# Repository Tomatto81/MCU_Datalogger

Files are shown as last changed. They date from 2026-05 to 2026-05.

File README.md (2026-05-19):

## ⚙️ MCU Data Logger – PCB Design with KiCad  

### 📋 Project Overview

**MCU Data Logger** is a custom PCB that records sensor or system data over time.

It's built around an **ATmega328P‑AU** microcontroller and uses an **EEPROM** (24LC1025) to keep the data even after power is removed. A **DS1337 real‑time clock** timestamps every entry, so you know exactly when something happened.

The board talks to the outside world through **UART, SPI, and I2C** – you can connect it to sensors, displays, or another microcontroller. I also brought out a few spare GPIOs in case you want to add more features later.

The whole design was done in **KiCad** using a **4‑layer stackup** (signal – GND – VCC – signal) to keep noise low and routing tidy.

### 🔧 Key Features

- **4-layer PCB** – Designed and routed in KiCad.
- **ATmega328P-AU** – Main microcontroller for processing and control.
- **💾 24LC1025 EEPROM** – Non‑volatile storage for logged data.
- **⏱️ DS1337 RTC** – Real‑time clock for accurate timestamps.
- **🔌 UART, SPI, I2C** – Multiple communication interfaces.
- **📈 Spare GPIOs** – Brought out for future expansion.

---

## 🔄 Project Flow  

1️⃣ **Microcontroller (ATmega328P-AU)**  
   - Handles all system operations and manages communication.  
   - Reads and writes data to EEPROM for storage.  
   
2️⃣ **RTC Module (DS1337)**  
   - Provides accurate timestamps for logged data.  
   - Communicates via I2C with the MCU.  
   
3️⃣ **EEPROM Storage (24LC1025)**  
   - Stores logged data persistently.  
   - Connected over I2C for data transfer.  

4️⃣ **Communication Interfaces**  
   - **UART**: Serial communication for debugging/logging.  
   - **SPI & I2C**: Expandability for additional peripherals.  

5️⃣ **Power Management & PCB Layout**  
   - Designed for stable operation with proper power routing.  
   - Optimized signal paths to reduce interference and improve reliability.  

--- 

## 🖼️ PCB Design & Visualizations

### 1️⃣ Top Copper Layer
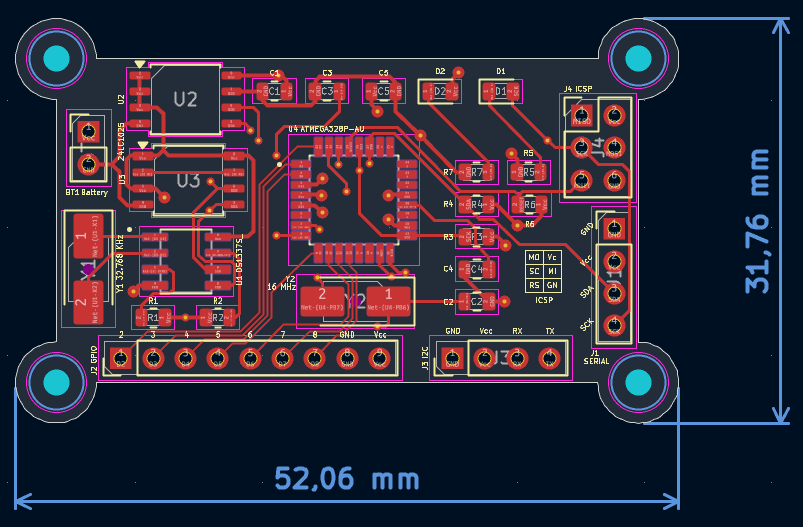
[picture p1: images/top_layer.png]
Top Copper Layer


### 2️⃣ Bottom Copper Layer
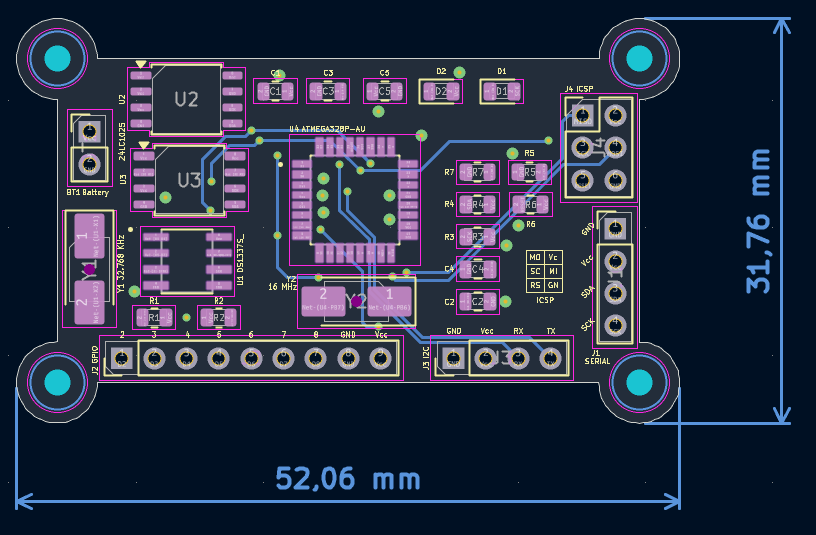
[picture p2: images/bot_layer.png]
Bottom Copper Layer
  

### 3️⃣ MCU Datalogger Schematic
MCU Datalogger Schematic  

### 4️⃣ Connectors Schematic
Connectors Schematic

### 5️⃣ 3D Model (Top & Bottom)
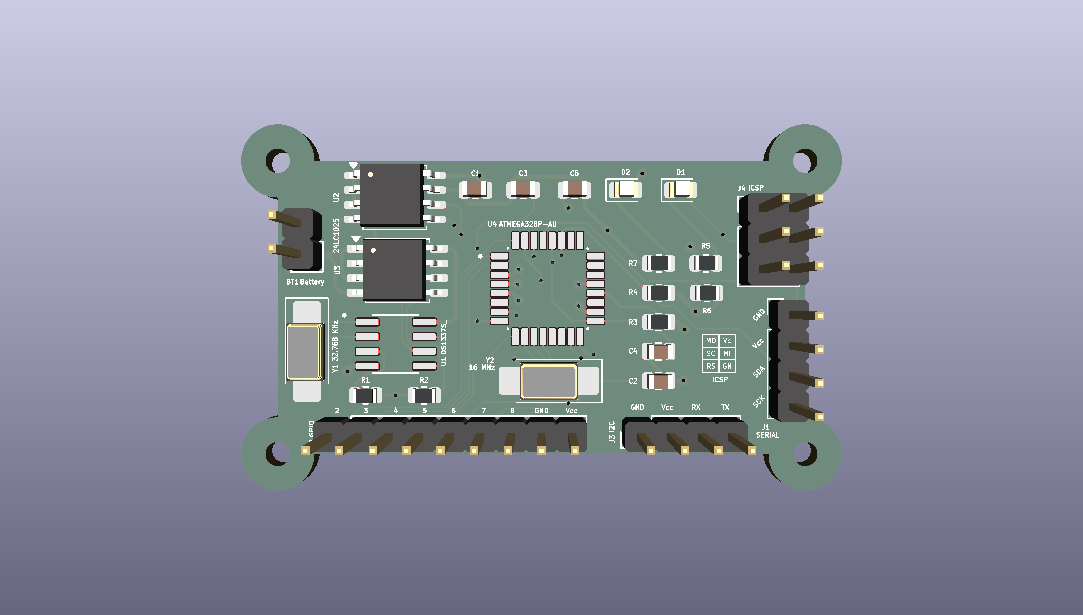
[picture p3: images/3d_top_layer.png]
3D Model - Top

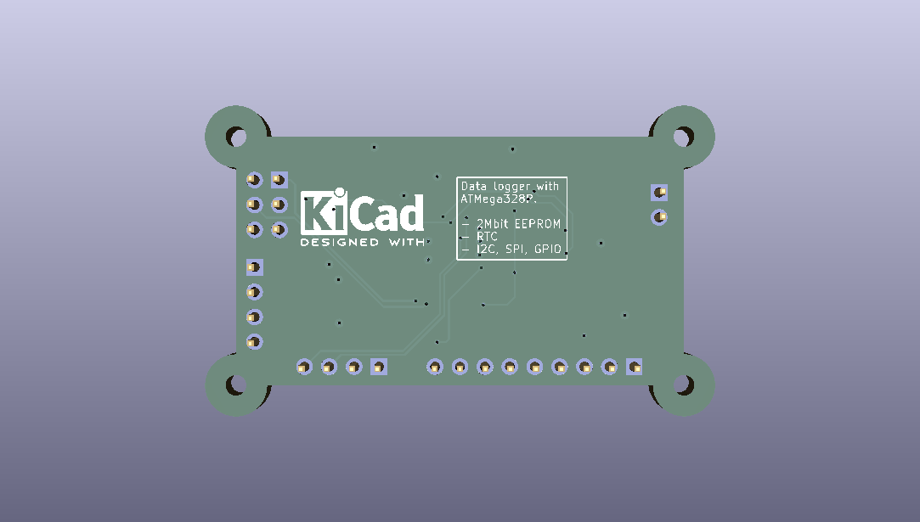
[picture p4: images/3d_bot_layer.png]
3D Model - Bottom


---

## 📥 Download & Build
The complete project files, including KiCad PCB designs and schematics, are available for download from my **GitHub repository**.

---

## 💬 Feedback & Suggestions
Please feel free to open an **issue** or leave a **comment**.

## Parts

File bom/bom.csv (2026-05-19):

 | Sourced | Placed | References | Value | Footprint | Quantity
1 |  |  | C1, C4, C5 | 100nF | C_0805_2012Metric | 3
2 |  |  | C2, C3 | 22pF | C_0805_2012Metric | 2
3 |  |  | R1, R2, R6 | 10K | R_0805_2012Metric | 3
4 |  |  | R3, R4 | 4.7K | R_0805_2012Metric | 2
5 |  |  | R5, R7 | 330 | R_0805_2012Metric | 2
6 |  |  | D1, D2 | LED | LED_0805_2012Metric | 2
7 |  |  | U2, U3 | 24LC1025 | SOIC-8_5.3x5.3mm_P1.27mm | 2
8 |  |  | U1 | DS1337S_ | SOIC127P600X175-8N | 1
9 |  |  | U4 | ATMEGA328P-AU | QFP80P900X900X120-32N | 1
10 |  |  | Y1 | 32.768 KHz | Crystal_SMD_5032-2Pin_5.0x3.2mm_HandSoldering | 1
11 |  |  | Y2 | 16 MHz | Crystal_SMD_5032-2Pin_5.0x3.2mm_HandSoldering | 1
12 |  |  | BT1 | Battery | PinHeader_1x02_P2.54mm_Vertical | 1
13 |  |  | J1, J3 | Conn_01x04_Pin | PinHeader_1x04_P2.54mm_Vertical | 2
14 |  |  | J2 | Conn_01x09_Pin | PinHeader_1x09_P2.54mm_Vertical | 1
15 |  |  | J4 | Conn_02x03_Odd_Even | PinHeader_2x03_P2.54mm_Vertical | 1

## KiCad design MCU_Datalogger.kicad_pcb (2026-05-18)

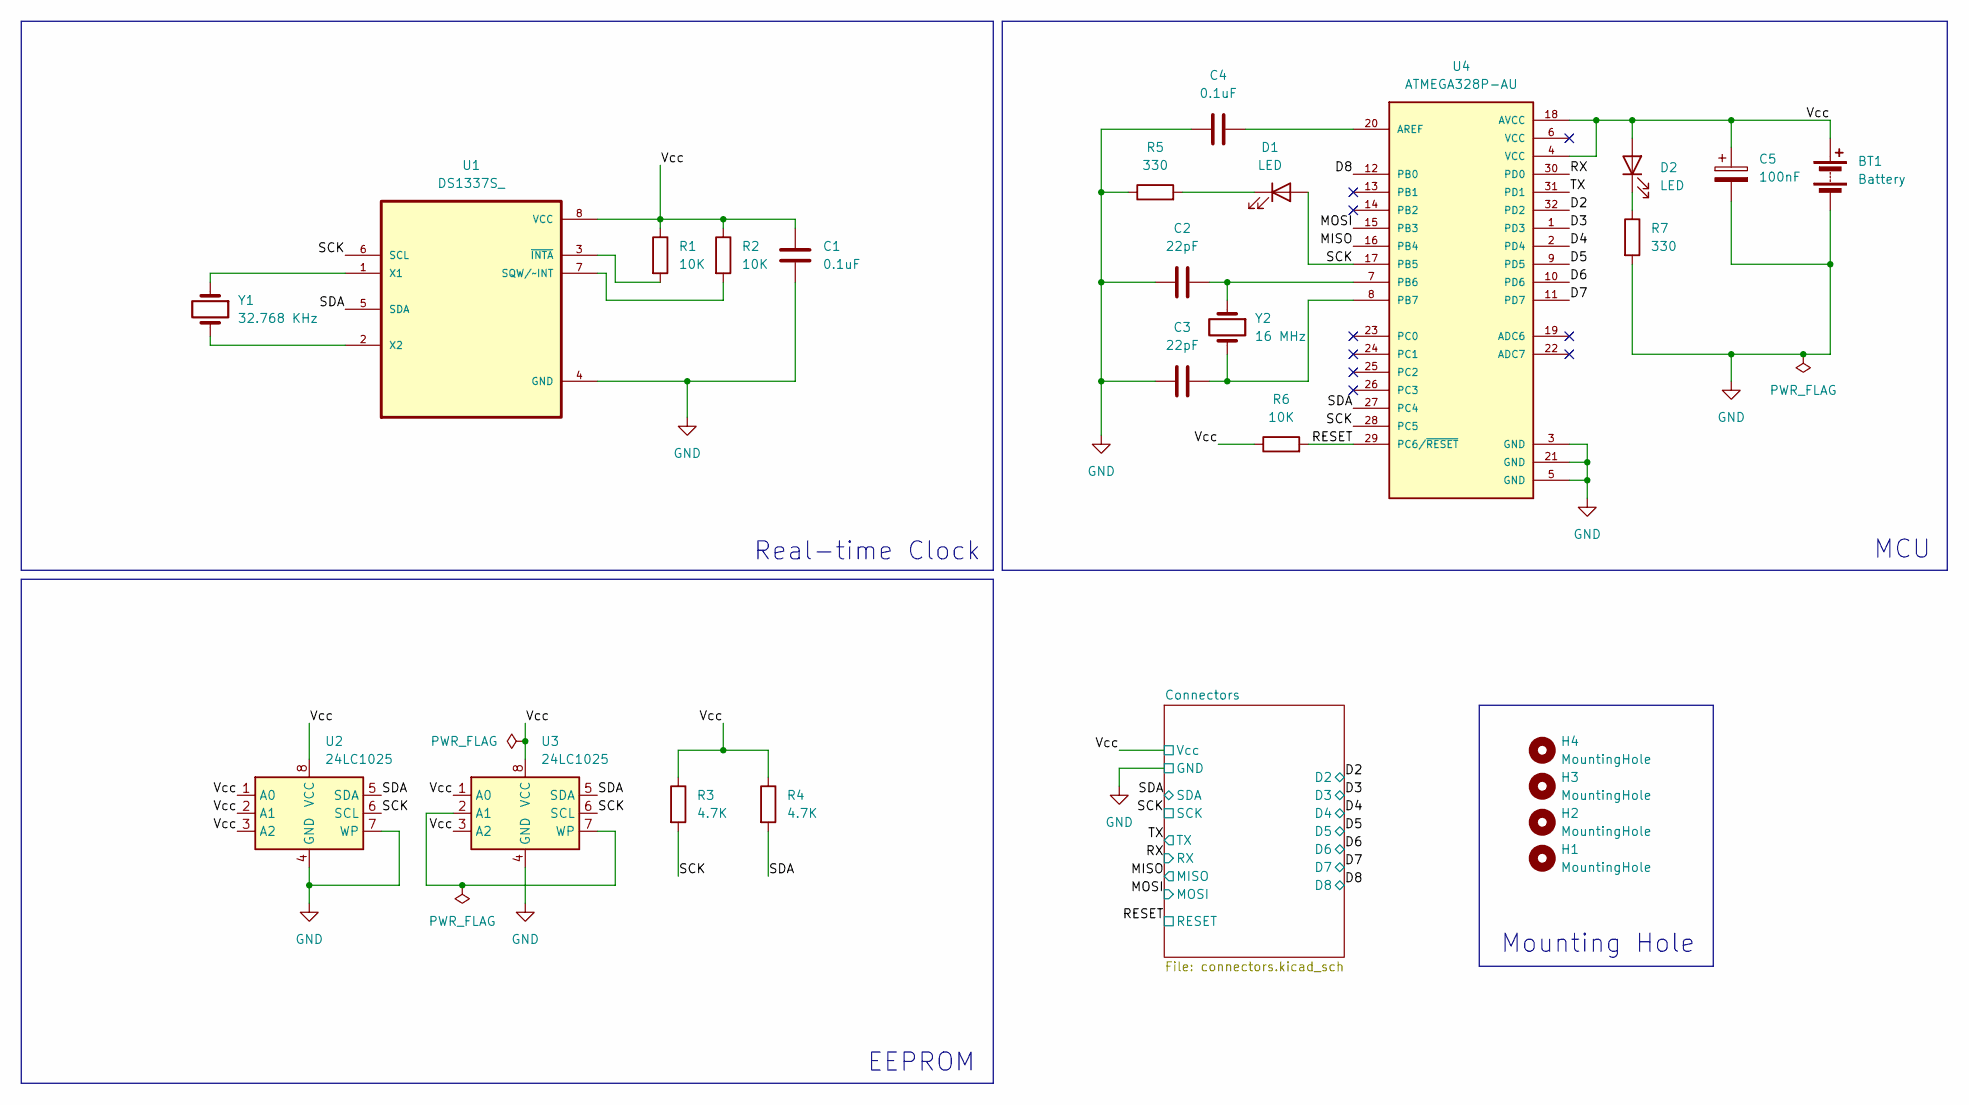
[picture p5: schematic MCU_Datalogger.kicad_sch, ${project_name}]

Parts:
BT1: Battery; PinHeader_1x02_P2.54mm_Vertical
C1, C4: 0.1uF; C_0805_2012Metric
C2, C3: 22pF; C_0805_2012Metric
C5: 100nF; C_0805_2012Metric
D1, D2: LED; LED_0805_2012Metric
H1, H2, H3, H4: MountingHole; MountingHole_2.1mm
R1, R2, R6: 10K; R_0805_2012Metric
R3, R4: 4.7K; R_0805_2012Metric
R5, R7: 330; R_0805_2012Metric
U1: DS1337S_; SOIC127P600X175-8N
U2, U3: 24LC1025; SOIC-8_5.3x5.3mm_P1.27mm
U4: ATMEGA328P-AU; QFP80P900X900X120-32N; PARTREV 8271A
Y1: 32.768 KHz; Crystal_SMD_5032-2Pin_5.0x3.2mm_HandSoldering
Y2: 16 MHz; Crystal_SMD_5032-2Pin_5.0x3.2mm_HandSoldering

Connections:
/D2: U4.32 (PD2); also elsewhere on the board
/D3: U4.1 (PD3); also elsewhere on the board
/D4: U4.2 (PD4); also elsewhere on the board
/D5: U4.9 (PD5); also elsewhere on the board
/D6: U4.10 (PD6); also elsewhere on the board
/D7: U4.11 (PD7); also elsewhere on the board
/D8: U4.12 (PB0); also elsewhere on the board
/MISO: U4.16 (PB4); also elsewhere on the board
/MOSI: U4.15 (PB3); also elsewhere on the board
/RESET: R6.2, U4.29 (PC6/~RESET); also elsewhere on the board
/RX: U4.30 (PD0); also elsewhere on the board
/SCK: D1.2 (A), R3.2, U1.6 (SCL), U2.6 (SCL), U3.6 (SCL), U4.17 (PB5), U4.28 (PC5); also elsewhere on the board
/SDA: R4.2, U1.5 (SDA), U2.5 (SDA), U3.5 (SDA), U4.27 (PC4); also elsewhere on the board
/TX: U4.31 (PD1); also elsewhere on the board
/Vcc: BT1.1 (+), C1.1, C5.1, D2.2 (A), R1.1, R2.1, R3.1, R4.1, R6.1, U1.8 (VCC), U2.1 (A0), U2.2 (A1), U2.3 (A2), U2.8 (VCC), U3.1 (A0), U3.3 (A2), U3.8 (VCC), U4.4 (VCC), U4.18 (AVCC); also elsewhere on the board
GND: BT1.2 (-), C1.2, C2.2, C3.2, C4.1, C5.2, R5.1, R7.2, U1.4 (GND), U2.4 (GND), U2.7 (WP), U3.4 (GND), U4.3 (GND), U4.5 (GND), U4.21 (GND); also elsewhere on the board
unnamed: D1.1 (K), R5.2
unnamed: D2.1 (K), R7.1
unnamed: R2.2, U1.7 (SQW/~INT)
unnamed: U1.1 (X1), Y1.1
unnamed: U1.2 (X2), Y1.2
unnamed: R1.2, U1.3 (~INTA)
unnamed: U3.2 (A1), U3.7 (WP)
unnamed: C4.2, U4.20 (AREF)
unnamed: C2.1, U4.7 (PB6), Y2.1
unnamed: C3.1, U4.8 (PB7), Y2.2

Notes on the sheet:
EEPROM
Real-time Clock
Mounting Hole
MCU

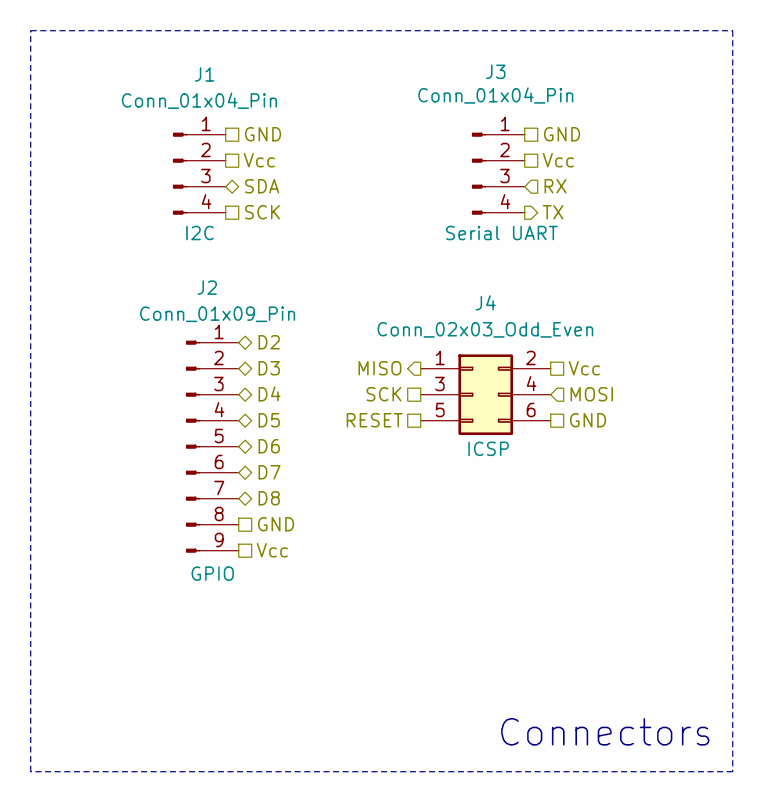
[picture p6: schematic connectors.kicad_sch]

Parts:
J1, J3: Conn_01x04_Pin; PinHeader_1x04_P2.54mm_Vertical
J2: Conn_01x09_Pin; PinHeader_1x09_P2.54mm_Vertical
J4: Conn_02x03_Odd_Even; PinHeader_2x03_P2.54mm_Vertical

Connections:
/D2: J2.1; also elsewhere on the board
/D3: J2.2; also elsewhere on the board
/D4: J2.3; also elsewhere on the board
/D5: J2.4; also elsewhere on the board
/D6: J2.5; also elsewhere on the board
/D7: J2.6; also elsewhere on the board
/D8: J2.7; also elsewhere on the board
/MISO: J4.1; also elsewhere on the board
/MOSI: J4.4; also elsewhere on the board
/RESET: J4.5; also elsewhere on the board
/RX: J3.3; also elsewhere on the board
/SCK: J1.4, J4.3; also elsewhere on the board
/SDA: J1.3; also elsewhere on the board
/TX: J3.4; also elsewhere on the board
/Vcc: J1.2, J2.9, J3.2, J4.2; also elsewhere on the board
GND: J1.1, J2.8, J3.1, J4.6; also elsewhere on the board

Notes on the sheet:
Connectors

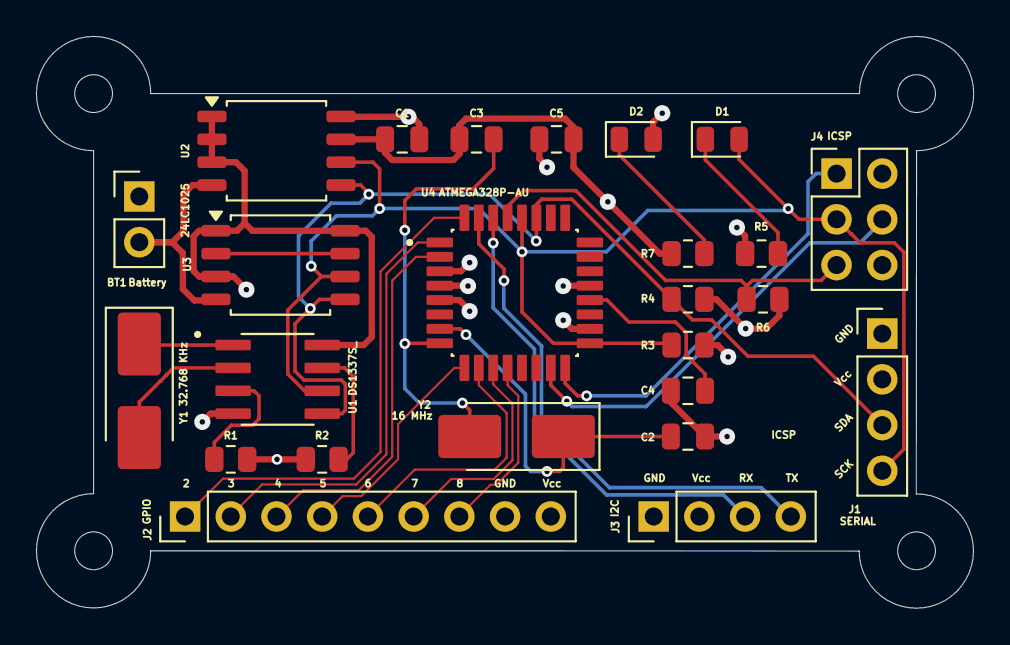
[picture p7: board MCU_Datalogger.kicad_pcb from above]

Board: 4 copper layers, 52.1 x 31.8 mm, 29 parts (0 on the bottom side), 26 nets.

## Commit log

2026-04-26 First commit of new project.
    [MCU Datalogger.kicad_pcb, MCU Datalogger.kicad_sch]
2026-04-26 Setup of the schematic editor for the new project.
2026-05-04 Added required symbols to the schematic sheets.
    [MCU Datalogger.kicad_sch]
2026-05-05 Completed wiring of main sheet.
    [MCU Datalogger.kicad_sch, connectors.kicad_sch]
2026-05-14 Update setup for schematic editor.
    [MCU Datalogger.kicad_sch]
2026-05-14 Completed schematic editor
    [MCU Datalogger.kicad_sch, connectors.kicad_sch]
2026-05-14 Setup PCB Editor
    [MCU Datalogger.kicad_pcb]
2026-05-14 Completed placement of footprints
    [MCU Datalogger.kicad_pcb]
2026-05-14 Refined and completed outline
    [MCU Datalogger.kicad_pcb]
2026-05-16 Ready to manufacture version 1
    [MCU Datalogger.kicad_pcb]
2026-05-17 Completed 2-layer PCB Project
    [MCU Datalogger-B_Cu.gbl, MCU Datalogger-B_Mask.gbs, MCU Datalogger-B_Paste.gbp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]
2026-05-17 Remove gerber folder
    [MCU Datalogger-B_Cu.gbl, MCU Datalogger-B_Mask.gbs, MCU Datalogger-B_Paste.gbp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]
2026-05-17 Rename project folder to remove space
    [MCU Datalogger.kicad_pcb, freerouting.dsn, temp-freerouting.dsn]
2026-05-17 Completed 4-layer PCB routing
    [MCU Datalogger.kicad_pcb, MCU_Datalogger.kicad_pcb, MCU_Datalogger.kicad_sch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]
2026-05-17 Completed 4-layer PCB
    [MCU_Datalogger.kicad_pcb]
2026-05-18 Small change to schematic
    [MCU Datalogger.kicad_sch]
2026-05-18 Update schematic
2026-05-18 Optimize PCB routing
    [MCU Datalogger.kicad_pcb]
2026-05-18 Fix folder
    [MCU Datalogger.kicad_pcb, MCU Datalogger.kicad_sch]
2026-05-18 Improve PCB design, add images folder, and bom folder
    [MCU_Datalogger.kicad_pcb, MCU_Datalogger.kicad_sch, connectors.kicad_sch]
2026-05-19 add bom.csv
    [bom.csv]
